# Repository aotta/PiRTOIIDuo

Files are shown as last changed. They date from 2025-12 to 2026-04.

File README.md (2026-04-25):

# PiRTOIIDuo
New PiRTO multicart for Intellivision with JLP support, based on Raspberry Pico2 

PiRTO II DUO is the new version of my PiRTO multicart DIY yourself based now on a Raspberry Pi Pico2 for using double RAM.

This version support Intellivision bin+cfg games, including the JLP acceleration and savegames features.
It works with all games i testes since now, except for "Onion" (it's a big rom and i think it will need next pico3 ;) )

changelog:
v.1.00 - initial release

v.1.01 - bugfix in parsing cfg

v.1.02 - added parsing for "jlp_accel" params, improved overclock for "Onion"

v.1.03 - increaded RAMSIZE to 0x4000 from 0x2000, bug fixed for YM-Player

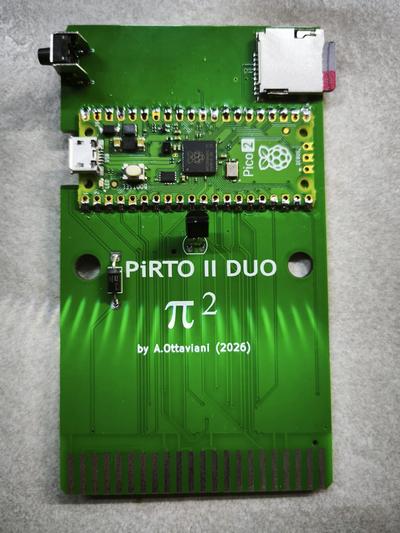
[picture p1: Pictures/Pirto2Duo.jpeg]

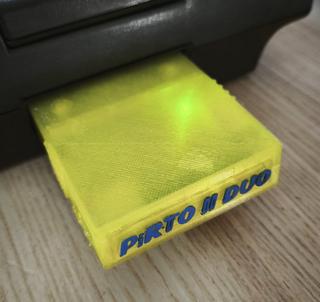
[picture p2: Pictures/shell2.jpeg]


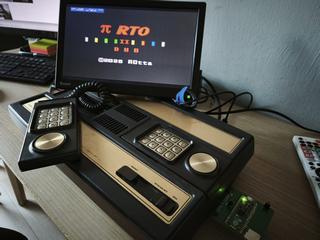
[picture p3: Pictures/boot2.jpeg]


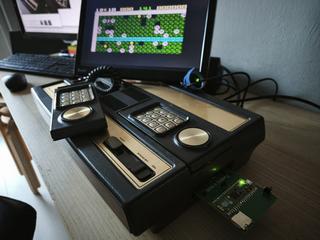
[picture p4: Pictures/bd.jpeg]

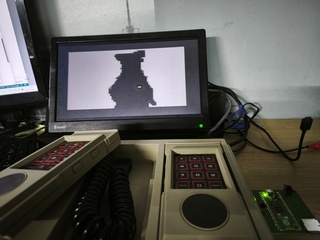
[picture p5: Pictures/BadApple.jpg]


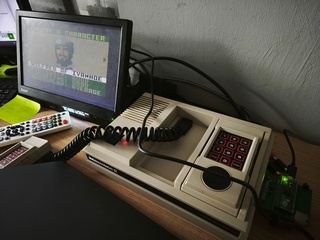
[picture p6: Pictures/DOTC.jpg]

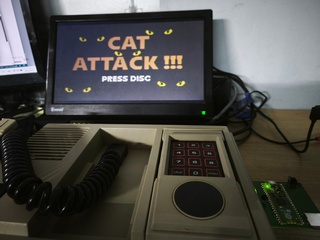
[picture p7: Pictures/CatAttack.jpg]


Kicad project and gerbers files for the pcb are in the PCB folder, you need only a diode, a push buttons for resetting the cart if needed or want restart, and the micro SDCard holder. 
Add you pico2, and flash the firmware ".uf2" in the Pico by connecting it while pressing button on Pico and drop it in the opened windows on PC.
Use the SDCard to store "BIN" and "CFG“ files  into.

3D files for shell coming soon!

More info on AtariAge forum: [https://forums.atariage.com/](https://forums.atariage.com/topic/386798-pirto-ii-duo-powered-by-pico2-with-jlp-support/)

Even if the diode should protect your console, **DO NOT CONNECT PICO WHILE INSERTED IN A POWERED ON CONSOLE!**
You can use any schottky diode, i usually put 1n4148

## Credits
This upgrade is dedicated to Mariella, with love and gratitude for trusting me and encouraging me to never give up

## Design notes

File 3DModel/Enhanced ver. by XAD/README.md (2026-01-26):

Here are some improvements that i have made to the PiRTO-II Duo cartridge cover:

- Reduced the hole for inserting the Mini SD Card. (Unless you have fingers big as sausages, you can easily remove and insert the Mini SD Card. I've seen much worse situations.)
- Added new PCB support bracket. (When inserting the Mini SD Card, the PCB flexed downward)
- Added hole for the Raspberry Pi Pico2 button. (Useful for updating the PiRTO-II Duo without opening the cartridge)
- Added hole for the USB connector. (Useful for updating the PiRTO-II Duo without opening the cartridge)
- Increased thickness of the front/top internal cartridge support.
- Slightly narrowed the hole for resetting/restarting the cartridge to use the button cover.

=-=-=-=-=-=-=-=-=-=-=-=-=-=-=-=-=-=-=-=-=-=-=-=-=-=-=-=-=-=-=-=-=-=-=-=-=-=-=-=-=-=-=-=-=-=-=-=-=-=-=-=-=-=-=-=-=-=-=-=-=-=-=-=-=-=

Ecco alcune migliorie che ho fatto alla cover della cartuccia PiRTO-II Duo.

- Ridotto il foro per inserire la Mini SDCard. (Almeno che tu non abbia della dita grosse come una salsicca si riesce benissimo a rimuovere e inserire la Mini SDCard,  ho visto situazioni molto peggiori)
- Aggiunto nuovo supporto per il PCB. (infilando la Mini SDCard il pcb si fletteva in basso)
- Aggiunto foro per il pulsante della Raspberry Pi Pico2. (utile per aggiornare la PiRTO-II Duo senza aprire la cartuccia)
- Aggiunto foro per il connettore USB.  (utile per aggiornare la PiRTO-II Duo senza aprire la cartuccia)
- Aumentato lo spessore del supporto interno frontale/superiore della cartuccia.
- Ristretto leggermente il foro del reset/restart cartuccia per utilizzare il copri pulsante.

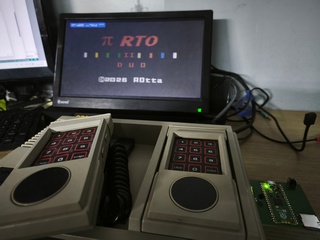
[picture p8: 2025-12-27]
Pictures/PiRTOIIDuo.jpg

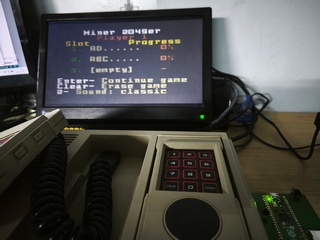
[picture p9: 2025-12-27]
Pictures/Miner2049.jpg

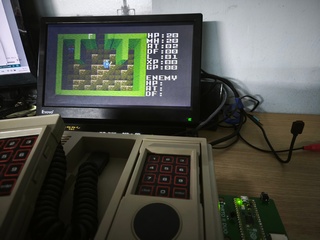
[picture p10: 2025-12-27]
Pictures/TalesofDragon.jpg

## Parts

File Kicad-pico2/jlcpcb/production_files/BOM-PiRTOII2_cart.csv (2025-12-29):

Comment | Designator | Footprint | LCSC | Quantity
1n5819 | D1 | D_DO-41_SOD81_P10.16mm_Horizontal | C2474 | 1
BC547 | Q1 | TO-92L_HandSolder | C2092 | 1
BTN_RESET_PICO | SW1 | SW_Tactile_SPST_Angled_PTS645Vx83-2LFS | C918856 | 1
Micro_SD_Card | J3 | J_SD_Card-micro_socket_A | C393941 | 1
PICO | U1 | RPi_Pico_SMD_TH | C41407547 | 1
EDGE_CONN | CN1 | Intellivision_Edge_Connector |  | 1

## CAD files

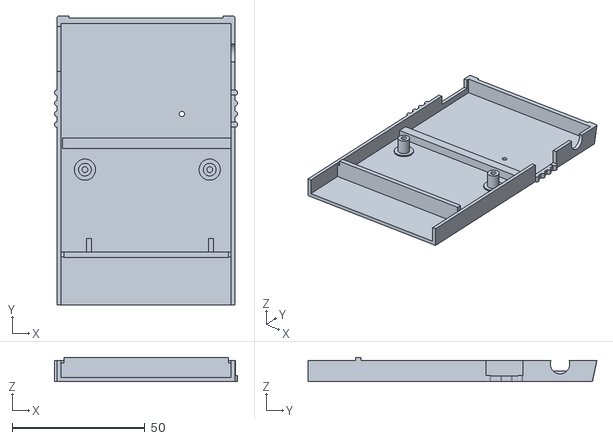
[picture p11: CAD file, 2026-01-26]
3DModel/Enhanced ver. by XAD/PiRTOIIDuo_Cart-Top_(Meshed)-Xad_Nightfall-v2.stl
69.0 x 108.9 x 9.18

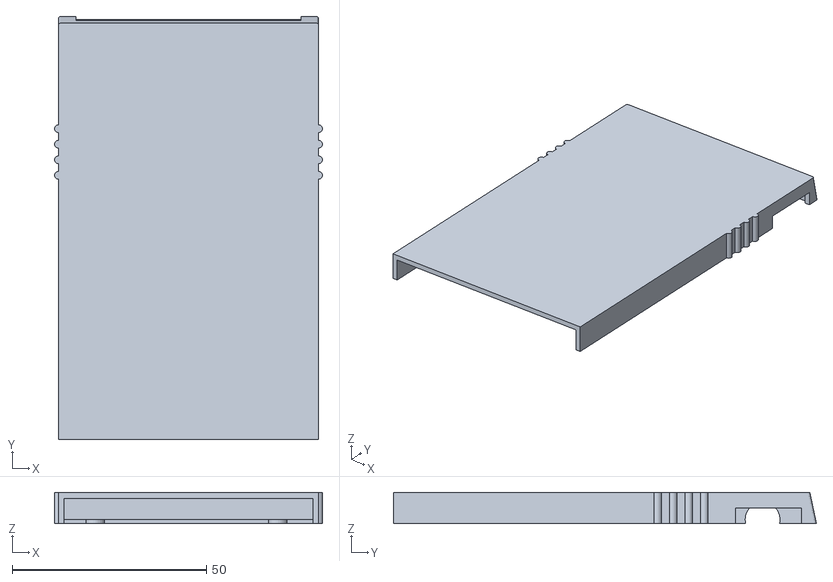
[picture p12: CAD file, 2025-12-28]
3DModel/Original/PiRTOIIDuo_Cart-Top (Meshed).stl
69.0 x 108.9 x 8.00

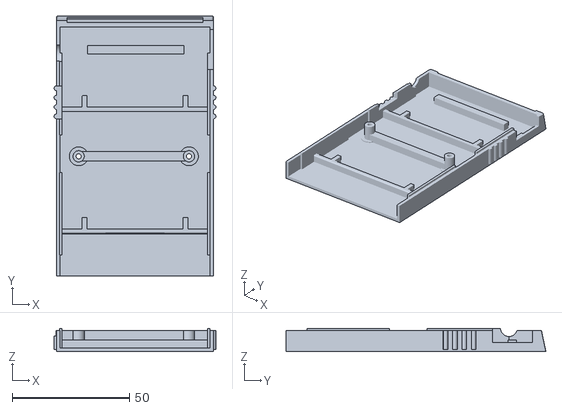
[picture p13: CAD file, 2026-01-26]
3DModel/Enhanced ver. by XAD/PiRTOIIDuo_Cart-Bottom_(Meshed)-Xad_Nightfall-v2.stl
69.0 x 110.8 x 10.00

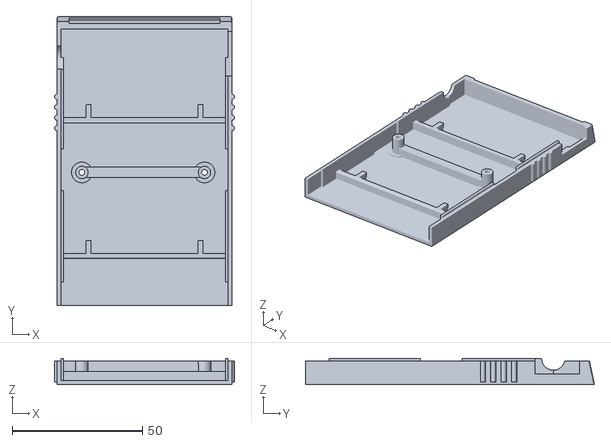
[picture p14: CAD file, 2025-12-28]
3DModel/Original/PiRTOIIDuo_Cart-Bottom (Meshed).stl
69.0 x 110.8 x 10.0

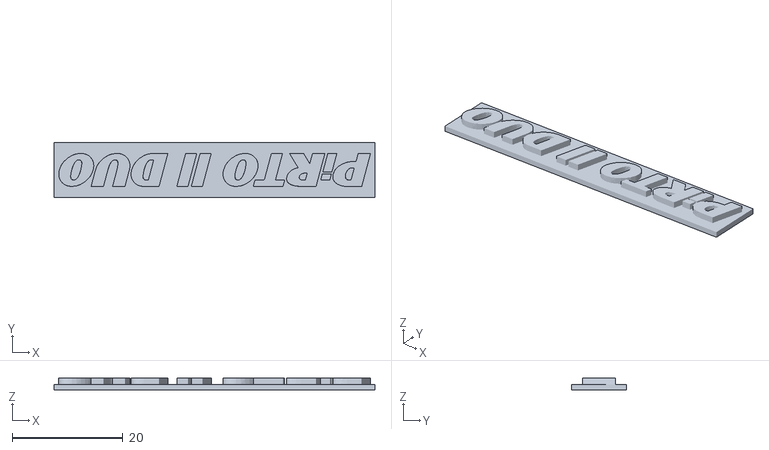
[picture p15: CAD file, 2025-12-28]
3DModel/Original/PiRTOIIDuo_Cart-Logo (Meshed).stl
58.0 x 10.0 x 2.10

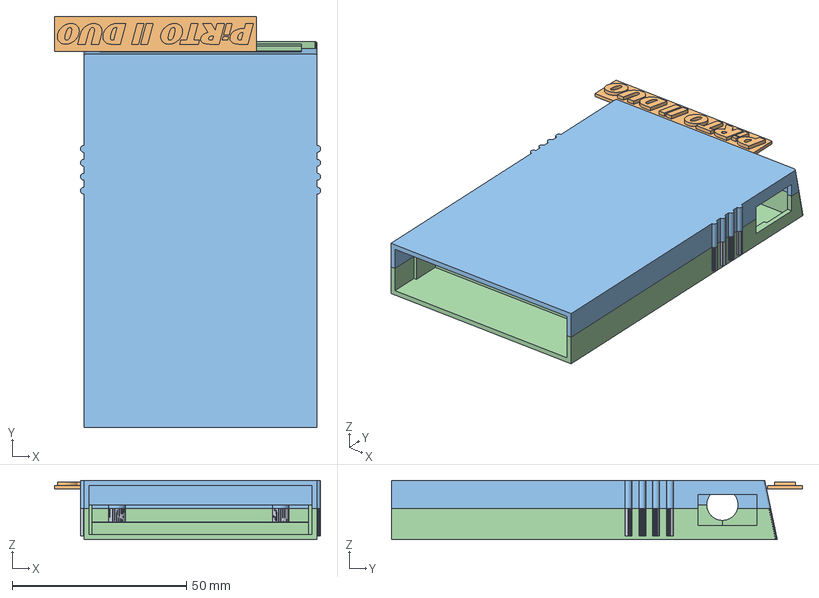
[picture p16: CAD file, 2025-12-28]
3DModel/Original/PiRTOIIDuo_Cart.FCStd
76.5 x 118.0 x 17.0 mm
Bottom
Logo (Meshed)
Top (Meshed)
Bottom (Meshed)

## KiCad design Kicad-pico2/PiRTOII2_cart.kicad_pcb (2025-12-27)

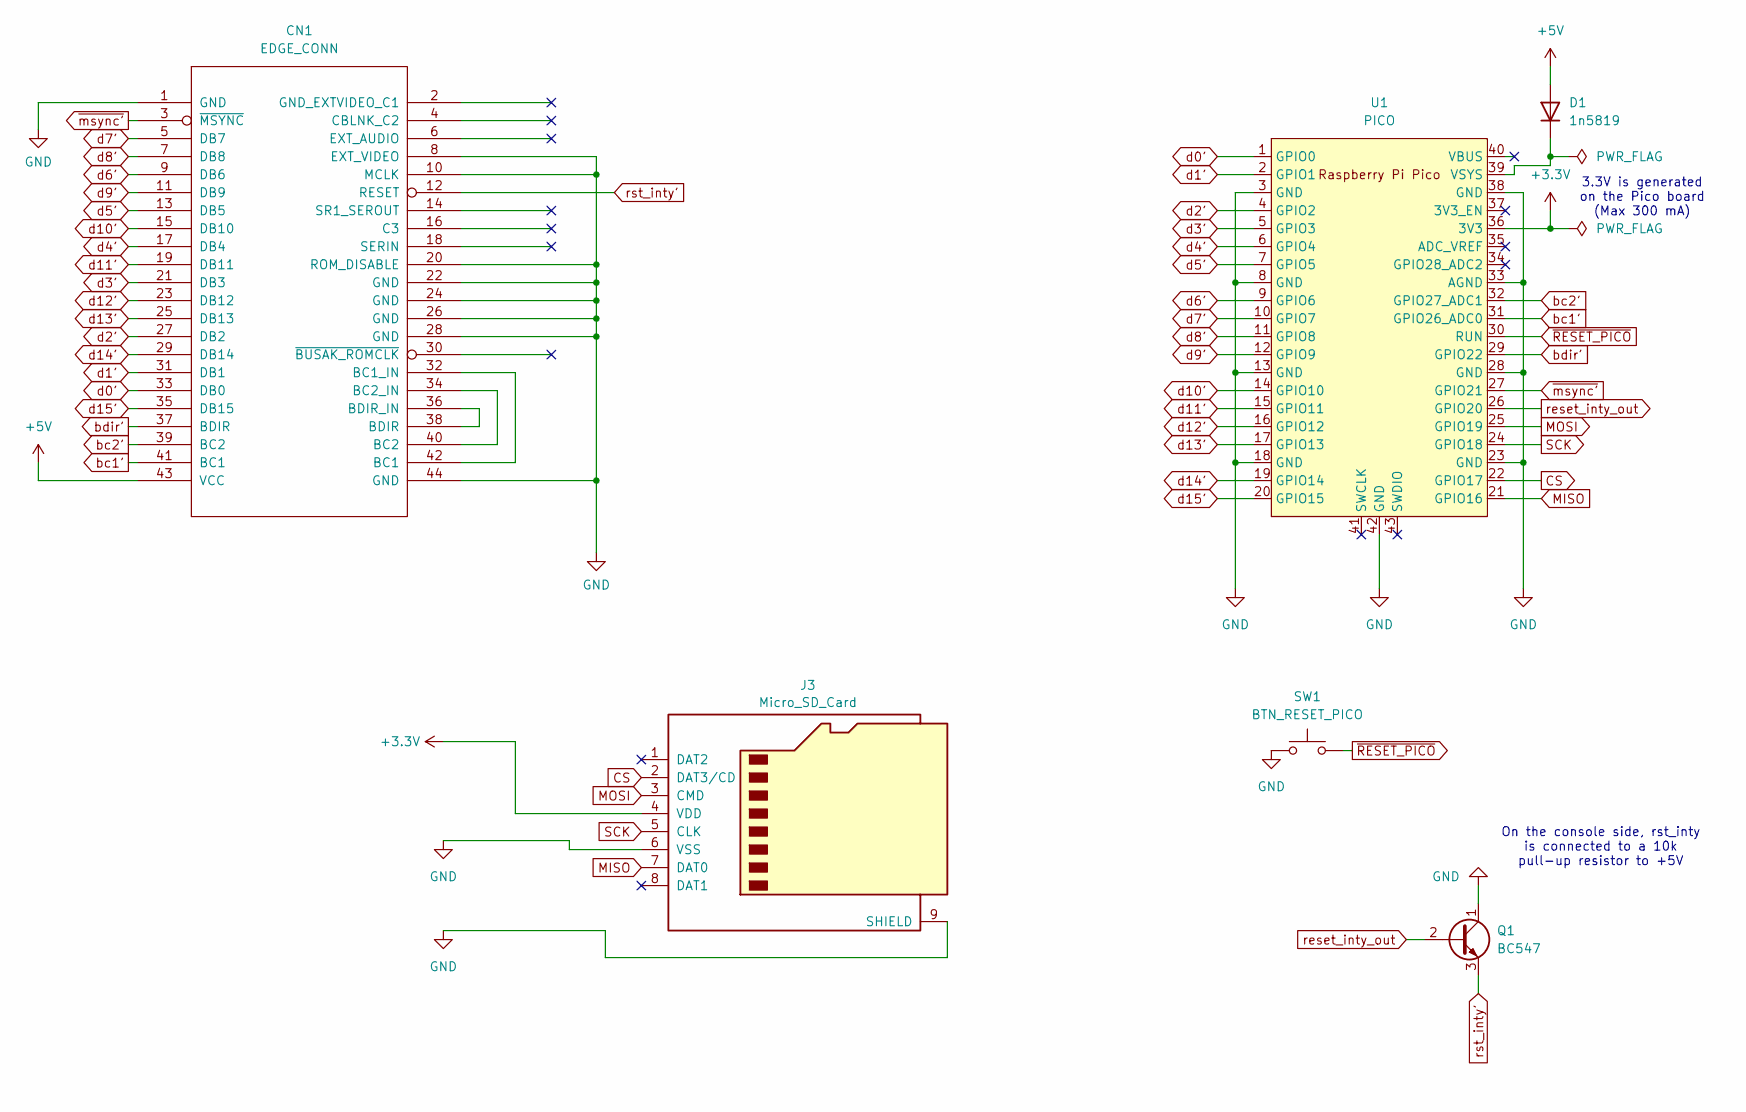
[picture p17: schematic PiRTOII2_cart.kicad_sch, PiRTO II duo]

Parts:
CN1: EDGE_CONN; Intellivision_Edge_Connector
D1: 1n5819; D_DO-41_SOD81_P10.16mm_Horizontal
J3: Micro_SD_Card; J_SD_Card-micro_socket_A
Q1: BC547; TO-92L_HandSolder
SW1: BTN_RESET_PICO; SW_Tactile_SPST_Angled_PTS645Vx83-2LFS
U1: PICO; RPi_Pico_SMD_TH

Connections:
+3.3V: J3.4 (VDD), U1.36 (3V3)
+5V: CN1.43 (VCC), D1.2 (A)
CS: J3.2 (DAT3/CD), U1.22 (GPIO17)
GND: CN1.1 (GND), CN1.8 (EXT_VIDEO), CN1.10 (MCLK), CN1.20 (ROM_DISABLE), CN1.22 (GND), CN1.24 (GND), CN1.26 (GND), CN1.28 (GND), CN1.44 (GND), J3.6 (VSS), J3.9 (SHIELD), Q1.1 (C), SW1.1, U1.3 (GND), U1.8 (GND), U1.13 (GND), U1.18 (GND), U1.23 (GND), U1.28 (GND), U1.33 (AGND), U1.38 (GND), U1.42 (GND)
MISO: J3.7 (DAT0), U1.21 (GPIO16)
MOSI: J3.3 (CMD), U1.25 (GPIO19)
unnamed: CN1.32 (BC1_IN), CN1.42 (BC1)
unnamed: CN1.34 (BC2_IN), CN1.40 (BC2)
unnamed: CN1.36 (BDIR_IN), CN1.38 (BDIR)
unnamed: D1.1 (K), U1.39 (VSYS)
SCK: J3.5 (CLK), U1.24 (GPIO18)
bc1': CN1.41 (BC1), U1.31 (GPIO26_ADC0)
bc2': CN1.39 (BC2), U1.32 (GPIO27_ADC1)
bdir': CN1.37 (BDIR), U1.29 (GPIO22)
d0': CN1.33 (DB0), U1.1 (GPIO0)
d1': CN1.31 (DB1), U1.2 (GPIO1)
d2': CN1.27 (DB2), U1.4 (GPIO2)
d3': CN1.21 (DB3), U1.5 (GPIO3)
d4': CN1.17 (DB4), U1.6 (GPIO4)
d5': CN1.13 (DB5), U1.7 (GPIO5)
d6': CN1.9 (DB6), U1.9 (GPIO6)
d7': CN1.5 (DB7), U1.10 (GPIO7)
d8': CN1.7 (DB8), U1.11 (GPIO8)
d9': CN1.11 (DB9), U1.12 (GPIO9)
d10': CN1.15 (DB10), U1.14 (GPIO10)
d11': CN1.19 (DB11), U1.15 (GPIO11)
d12': CN1.23 (DB12), U1.16 (GPIO12)
d13': CN1.25 (DB13), U1.17 (GPIO13)
d14': CN1.29 (DB14), U1.19 (GPIO14)
d15': CN1.35 (DB15), U1.20 (GPIO15)
reset_inty_out: Q1.2 (B), U1.26 (GPIO20)
rst_inty': CN1.12 (RESET), Q1.3 (E)
~RESET_PICO: SW1.2, U1.30 (RUN)
~msync': CN1.3 (~MSYNC), U1.27 (GPIO21)

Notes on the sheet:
3.3V is generated on the Pico board (Max 300 mA)
On the console side, rst_inty is connected to a 10k pull-up resistor to +5V

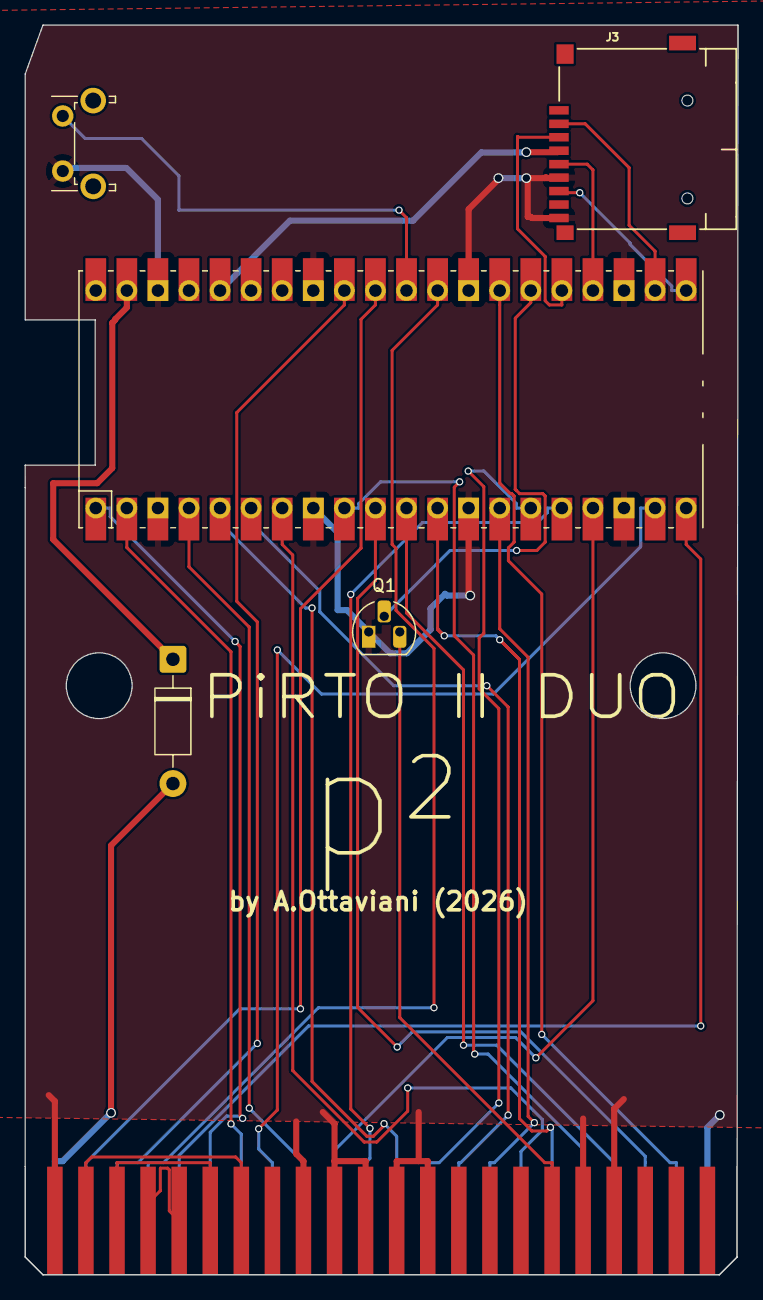
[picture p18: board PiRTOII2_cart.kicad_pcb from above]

Board: 2 copper layers, 58.3 x 102.1 mm, 6 parts (0 on the bottom side), 34 nets.

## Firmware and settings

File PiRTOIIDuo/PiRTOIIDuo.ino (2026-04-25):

/*
//////////////////////////////////////////////////////////////////////////////////////////
//
//                       PiRTO II DUO Flash MultiCART by Andrea Ottaviani 2024
//
//////////////////////////////////////////////////////////////////////////////////////////
//
//  Intellivision flash multicart based on Raspberry Pico2 board -
//  New PiRTO II version with JLP and savegame support
//  More info on https://github.com/aotta/ 
//  
// ***************************************************************************************
//   This upgrade is dedicated to Mariella, with love and gratitude  
//   for trusting me and encouraging me to never give up
// ***************************************************************************************
//
//  v.1.00 - First release 27/12/2025
//  v.1.01 - bug fixed in parsing .cfg with "build date"
//  v.1.02 - added parsing "jlp_accel" in .cfg 
//  v.1.03 - increaded RAMSIZE to 0x4000 from 0x2000, bug fixed for YM-Player
*/

//#define intydebug // for debug print on intyscreen
#define SD_BOARD 
//#define DEFAULT_BOARD 0

#include "hardware/gpio.h"
#include "pico/platform.h"
#include "pico/stdlib.h"
#include "hardware/vreg.h"
#include "pico/multicore.h"
#include "hardware/flash.h"
#include "hardware/sync.h"
#include "string.h"
#include "rom.h"
#include "dir_entry.hpp"
// include for Flash files
#include "SPI.h"
#include "SD.h"

// file system object from SdFat
File file;
File flashFile;
    

// Pico pin usage definitions
#define B0_PIN    0
#define B1_PIN    1
#define B2_PIN    2
#define B3_PIN    3
#define B4_PIN    4
#define B5_PIN    5
#define B6_PIN    6
#define B7_PIN    7
#define F0_PIN    8
#define F1_PIN    9
#define F2_PIN    10
#define F3_PIN    11
#define F4_PIN    12
#define F5_PIN    13
#define F6_PIN    14
#define F7_PIN    15
#define B0_PIN_MASK     0x00000001L     // gpio 0
#define B1_PIN_MASK     0x00000002L
#define B2_PIN_MASK     0x00000004L
#define B3_PIN_MASK     0x00000008L
#define B4_PIN_MASK     0x00000010L
#define B5_PIN_MASK     0x00000020L
#define B6_PIN_MASK     0x00000040L
#define B7_PIN_MASK     0x00000080L
#define F0_PIN_MASK     0x00000100L
#define F1_PIN_MASK     0x00000200L
#define F2_PIN_MASK     0x00000400L
#define F3_PIN_MASK     0x00000800L
#define F4_PIN_MASK     0x00001000L
#define F5_PIN_MASK     0x00002000L
#define F6_PIN_MASK     0x00004000L
#define F7_PIN_MASK     0x00008000L     // gpio 15 
#define RST_PIN   20
#define LED_PIN   25
#define RST_PIN_MASK    0x00100000L // gpio 20
#define LED_PIN_MASK    0x02000000L // gpio 25

// Pico pin usage masks

#ifdef DEFAULT_BOARD
  #define BDIR_PIN  16
  #define BC2_PIN   17
  #define BC1_PIN   18
  #define MSYNC_PIN 19
  #define BDIR_PIN_MASK   0x00010000L // gpio 16
  #define BC2_PIN_MASK    0x00020000L // gpio 17
  #define BC1_PIN_MASK    0x00040000L // gpio 18
  #define MSYNC_PIN_MASK  0x00080000L // gpio 19
  // Aggregate Pico pin usage masks
  #define ALL_GPIO_MASK  	0x021FFFFFL
#else
#ifdef SD_BOARD
   #define MSYNC_PIN 21
   #define BDIR_PIN  22
   #define BC1_PIN   26
   #define BC2_PIN   27
   
   // SD
   #define SD_MISO   16
   #define SD_CS     17
   #define SD_SCK    18
   #define SD_MOSI   19
   #define MSYNC_PIN_MASK  0x00200000L     // gpio 21
   #define BDIR_PIN_MASK   0x00400000L     // gpio 22
   #define BC1_PIN_MASK    0x04000000L     // gpio 26
   #define BC2_PIN_MASK    0x08000000L     // gpio 27
#endif
#endif



  #define BX_PIN_MASK      (B0_PIN_MASK | B1_PIN_MASK | B2_PIN_MASK | B3_PIN_MASK | B4_PIN_MASK | B5_PIN_MASK | B6_PIN_MASK | B7_PIN_MASK)
   #define FX_PIN_MASK     (F0_PIN_MASK | F1_PIN_MASK | F2_PIN_MASK | F3_PIN_MASK | F4_PIN_MASK | F5_PIN_MASK | F6_PIN_MASK | F7_PIN_MASK)
   #define BC1e2_PIN_MASK  (BC1_PIN_MASK | BC2_PIN_MASK)
   #define DATA_PIN_MASK   (BX_PIN_MASK | FX_PIN_MASK)
   #define BUS_STATE_MASK  (BDIR_PIN_MASK | BC1_PIN_MASK | BC2_PIN_MASK)
   #define ALWAYS_IN_MASK  (BUS_STATE_MASK | MSYNC_PIN_MASK)
   #define ALWAYS_OUT_MASK (LED_PIN_MASK|RST_PIN_MASK )


#define SET_DATA_MODE_OUT   gpio_set_dir_out_masked(DATA_PIN_MASK)
#define SET_DATA_MODE_IN    gpio_set_dir_in_masked(DATA_PIN_MASK)

#define resetLow()  gpio_set_dir(RST_PIN,true); gpio_put(RST_PIN,true); //  Pirto to INTV BUS ; RST Output set to 0
#define resetHigh() gpio_set_dir(RST_PIN,true); gpio_put(RST_PIN,false); // RST is INPUT; B->A, INTV BUS to TEENSY

// Inty bus values (BC1+BC2+BDIR) GPIO 26-27-22

#define BUS_NACT  0b000  //0
#define BUS_BAR   0b001  //1
#define BUS_IAB   0b010  //2
#define BUS_DWS   0b011  //3
#define BUS_ADAR  0b100  //4
#define BUS_DW    0b101  //5
#define BUS_DTB   0b110  //6
#define BUS_INTAK 0b111  //7

#define JLP_CRC_POLY 0xAD52

unsigned char busLookup[8];

char RBLo,RBHi;
#define BINLENGTH  1024*218//65536L
#define RAMSIZE  0x4000  // V.1.03 - increaded from 0x2000, bug fixed for YM-Player
#define FLASHSIZE  0x1800  //xx row da 96 0x1800 poi rimettere!!!

uint16_t ROM[BINLENGTH];
uint16_t RAM[RAMSIZE];

#define maxHacks 32
uint16_t HACK[maxHacks];
uint16_t HACK_CODE[maxHacks];

char curPath[256];
char path[256];
unsigned char files[255*70] = {0}; // 255*64 poi rimettere!!!!!!!!!!
unsigned char nomefiles[32*25] = {0};
int fileda=0,filea=0;
volatile char cmd=0;
char errorBuf[40];
bool cmd_executing=false;
volatile bool gameloaded=false;
volatile bool JLPOn=false;
volatile bool pagingOn=false;
volatile bool FlashingOn=false;
volatile unsigned int parallelBus2;
volatile uint8_t curBank;
volatile uint8_t curPage2;
unsigned int romLen;
volatile unsigned int ramfrom = 0;
volatile unsigned int ramto =   0;
unsigned int mapfrom[80];
unsigned int mapto[80];
unsigned int maprom[80];
int mapdelta[80];
unsigned int mapsize[80];
unsigned int addrto[80];
unsigned int RAMused = 0;
volatile bool RAM8 = false;
unsigned int tipo[80];  // 0-rom / 1-page / 2-ram
unsigned int page[80];  // page number
uint8_t curPage[16];
bool segmentedPage[16];


unsigned int slot;
// Variabili globali per il conteggio degli slot
unsigned int Slot0 = 0;  // Conteggio slot con tipo[] = 0
unsigned int Slot1 = 0;  // Conteggio slot con tipo[] = 1
int hacks;

int base=0x17f;

uint32_t selectedfile_size;    // BIN file size
char flashFilename[80];         // for check if directory
int lenfilename; 
char tiposcelta[9];
bool pressed=false;


////////////////////////////////////////////////////////////////////////////////////
//                     RESET
////////////////////////////////////////////////////////////////////////////////////
void resetCart() {
  gpio_init(MSYNC_PIN);
  gpio_set_dir(MSYNC_PIN,false);
  gpio_set_pulls(MSYNC_PIN,false,true);
  gpio_put(LED_PIN,false);
  resetHigh();
   sleep_ms(30);  // was 20 for Model II; 30 works for both
   resetLow();
  //sleep_ms(3);  // was 2 for Model II; 3 works for both
 
  //while ((gpio_get(MSYNC_PIN)==1)) ;
    
  sleep_ms(1);  // was 1 for Model II; 
  resetHigh();
  memset(curPage,0,sizeof(curPage));
  memset(segmentedPage,0,sizeof(segmentedPage));
  
  gpio_put(LED_PIN,true);
}


/*
 Theory of Operation
 -------------------
 Inty sends command to mcu on cart by writing to 50000 (CMD), 50001 (parameter) and menu (50002-50641) 
 Inty must be running from RAM when it sends a command, since the mcu on the cart will
 go away at that point. Inty polls 50001 until it reads $1.
*/

#pragma GCC push_options
#pragma GCC optimize ("O3")


/////////////////////////////////////////////////
void __time_critical_func(setup1()) {   //HandleBUS()
  unsigned int lastBusState, busState1;
  unsigned int busSt1, busSt2;
  unsigned int parallelBus;

  
//from data bus routine
  bool deviceAddress = false; 
  unsigned int dataOut;
  unsigned int dataWrite=0;
  unsigned char busBit;
  uint8_t seg;
  uint16_t curCRC = 0;

  // multicore_lockout_victim_init();	

  randomSeed(millis());
 

  sleep_ms(480);
  busState1 = BUS_NACT;
  lastBusState = BUS_NACT;
  
  dataOut=0;

    gpio_set_dir_in_masked(ALWAYS_IN_MASK);
    gpio_set_dir_out_masked(ALWAYS_OUT_MASK);
 
    // Initial conditions
    SET_DATA_MODE_IN;
   memset(curPage,0,sizeof(curPage));
  
while(1) {
    // Wait for the bus state to change
    
  do {
    } while (!((gpio_get_all() ^ lastBusState) & BUS_STATE_MASK));
    // We detected a change, but reread the bus state to make sure that all three pins have settled
     lastBusState = gpio_get_all();

      busState1 = ((lastBusState & BC1_PIN_MASK) >> (BC1_PIN - 2)) |
         ((lastBusState & BC2_PIN_MASK) >> (BC2_PIN - 1)) |
         ((lastBusState & BDIR_PIN_MASK) >> BDIR_PIN);

    busBit = busLookup[busState1];
    // Avoiding switch statements here because timing is critical and needs to be deterministic
    if (!busBit)
    {
      // -----------------------
      // DTB
      // -----------------------
      // DTB needs to come first since its timing is critical.  The CP-1600 expects data to be
      // placed on the bus early in the bus cycle (i.e. we need to get data on the bus quickly!)
	    if (deviceAddress)
      {
        // The data was prefetched during BAR/ADAR.  There isn't nearly enough time to fetch it here.
        // We can just output it.
        SET_DATA_MODE_OUT;
        gpio_put_masked(DATA_PIN_MASK,dataOut);
        asm inline ("nop;nop;nop;nop;nop;");
  
            //sukkopera 
       while((gpio_get_all() & BC1e2_PIN_MASK) == BC1e2_PIN_MASK) ;

       SET_DATA_MODE_IN;
      }
     }
    else
    {
      busBit >>= 1;
      if (!busBit)
      {
        // -----------------------
        // BAR, ADAR
        // -----------------------
	    if (busState1==BUS_ADAR) {
	     
        if (deviceAddress)  
      		{
        // The data was prefetched during BAR/ADAR.  There isn't nearly enough time to fetch it here.
        // We can just output it.
       
       	SET_DATA_MODE_OUT;
        gpio_put_masked(DATA_PIN_MASK,dataOut);
  //      asm inline ("nop;nop;nop;");
  
        while (((gpio_get_all() & BC1_PIN_MASK)>>BC1_PIN)); //wait BC1 go down 
        //asm inline (delWR); //150ns

         SET_DATA_MODE_IN;
        
      		}
	    }
        /// ELSE is BAR   
        // Prefetch data here because there won't be enough time to get it during DTB.
        // However, we can't take forever because of all the time we had to wait for
        // the address to appear on the bus.
        // We have to wait until the address is stable on the bus
        // waiting bus is stable 66 nop at 200mhz is ok/85 at 240
       
        SET_DATA_MODE_IN;
          parallelBus=0;
        while(((parallelBus=gpio_get_all()) & BDIR_PIN_MASK));  // wait DIR go low for finish BAR cycle 
       asm inline("nop;nop;nop;nop;");
       //asm inline (delRD); //150ns
    
      parallelBus = gpio_get_all()& 0xFFFF; 
      parallelBus2=parallelBus; //poivia
   // Load data for DTB here to save time

      deviceAddress = false;
      if (((parallelBus>=0x8000)&&(parallelBus<=0x9fff))&&(JLPOn)) {  
            deviceAddress = true;
            dataOut=RAM[parallelBus-0x8000];
        if ((parallelBus>=0x802d)&&(parallelBus<=0x802f)) {  //handling flashing command here to avoid de-sync
          if (!FlashingOn) {
            dataOut=0xffff;   //non togliere!!!
          } 
        }   
      } 
      else 
      {  //not jlp
      //  curBank=99;
          
          for (int8_t i=0; i < slot; i++) {
            if (((parallelBus - maprom[i]) <= mapsize[i])){
              deviceAddress = true;     
              if (tipo[i]==2) {
                 dataOut=RAM[parallelBus-ramfrom];
                deviceAddress = true;
                break;
              }
              if (tipo[i]==0) {
                  dataOut=ROM[(parallelBus - mapdelta[i])];
                  break;
              }
              if (tipo[i]==1) {
                seg=(parallelBus>>12)&0xf;   
                if (page[i]==curPage[seg]) {
                  dataOut=ROM[(parallelBus - mapdelta[i])];
                  break;
                } else {dataOut=0xffff;}
              }
            } 
          }
          
      } //if not jlp
        if (hacks>0) {
          for (int i=0; i<maxHacks;i++) {
            if (parallelBus==HACK[i]) {
              dataOut=HACK_CODE[i];
              deviceAddress = true;
	          }
            break;
          }
        } 
      }
      else
      {
         busBit >>= 1;
        if (!busBit)
        {
          // -----------------------
          // DWS WRITE
          // -----------------------
          SET_DATA_MODE_IN;

            if ((pagingOn)&&((parallelBus&0xfff)==0x0fff)) {
              if ((((dataWrite=gpio_get_all() & 0xffff) >> 4) & 0xff) == 0xA5) {
                seg=(parallelBus>>12)&0xf;   
                curPage[seg]=dataWrite & 0xf;
                curPage2=curPage[seg];
              }
            } //else // keep it!!
           if ((deviceAddress)) {
                //  asm inline ("nop;nop;nop;");
            dataWrite = gpio_get_all() & 0xFFFF; 
            if (((parallelBus>=0x8000)&&(parallelBus<=0x9fff))&& JLPOn) {
          //  if (((parallelBus>=0x8000)&&(parallelBus<=0x9fff))) {
              RAM[parallelBus-0x8000]=dataWrite;  
              if (parallelBus==0x9ffc) { // ha scritto 9ffc
                curCRC=RAM[0x1ffd];
                curCRC ^= RAM[0x1ffc];
                for (int i = 0; i < 16; i++) {
                  curCRC = (curCRC >> 1) ^ (curCRC & 1 ? 0xAD52 : 0);
                }
                RAM[0x1ffd]=curCRC;
                }
            } else
             { 
            if ((parallelBus>=ramfrom)&&(parallelBus<=ramto)) {
              if (RAM8) {
                RAM[parallelBus-ramfrom]=dataWrite & 0xFF;
              } else {
                RAM[parallelBus-ramfrom]=dataWrite;
              }
            } 
           }
          }
         else
        {
         // -----------------------
         // NACT, IAB, DW, INTAK
         // -----------------------
         // reconnect to bus
           SET_DATA_MODE_IN;
        }
        
        }
      } 
    }    
  }
} 

#pragma GCC pop_options


////////////////////////////////////////////////////////////////////////////////////
//                     Error(N)
////////////////////////////////////////////////////////////////////////////////////
void error(int numblink){
  Serial.print("Error ");
  Serial.println(numblink);
  while(1){
    gpio_set_dir(25,GPIO_OUT);
    
    for(int i=0;i<numblink;i++) {
      gpio_put(25,true);
      sleep_ms(600);
      gpio_put(25,false);
      sleep_ms(500);
      Serial.print("Error ");
      Serial.println(numblink);
    }
  sleep_ms(2000);
  }
}

/////////////////////////////////
// print on mfile on inty
////////////////////////////////
void printInty(char *temp) {
  for (int i=0;i<120;i++) RAM[0x17f+i]=0;
  for (int i=0;i<60;i++) {
    RAM[0x17f+i*2]=temp[i];
    if (temp[i]==0) {
      RAM[0x17f+i*2]='*';
      break;
    }
  }
  sleep_ms(1000);
} 
int read_directory(char *path) {
  //  if (path[0]==0) strcpy(path,'/');
    Serial.print("Read_directory: ");
    Serial.println(path);
    int ret = 0;
    num_dir_entries = 0;
    DIR_ENTRY *dst = (DIR_ENTRY *)&files[0];

    File dir=SD.open(path, O_RDONLY);
    if (dir) {
        File file;
        while (num_dir_entries < 90 && (file= dir.openNextFile())) {
            char filename[60];
            String(file.name()).toCharArray(filename,60);
            //Serial.println(filename);
            if (strcmp(filename, ".") == 0 || strcmp(filename, "..") == 0) {
                file.close();
                continue;
            }
            
            if ((strcmp(filename,"System Volume Information")==0) ||
            (strcmp(filename,"FOUND.000")==0))
            {
              // Serial.print(filename);Serial.println(" skipped!");
                file.close();
                continue;
            }
  
            dst->isDir = file.isDirectory();
            if (!dst->isDir && !is_valid_file(filename)) {
                file.close();
                continue;
            }
            
            // Usa lo stesso nome per entrambi i campi
            strncpy(dst->long_filename, filename, 31);
            dst->long_filename[31] = 0;
            strncpy(dst->filename, filename, 24);
            dst->filename[24] = 0;
            
            dst->full_path[0] = 0;
            dst++;
            num_dir_entries++;
            
            file.close();
        }
        dir.close();
        
        qsort((DIR_ENTRY *)&files[0], num_dir_entries, sizeof(DIR_ENTRY), entry_compare);
        ret = 1;
    }
    else {
        Serial.println("Can't read directory");
    }
    
    return ret;
}
/////////////////////////////////////////////////////////////////////////////////////////
///////////////////////////////* load file in  ROM */////////////////////////////////////
/////////////////////////////////////////////////////////////////////////////////////////

void load_file(char *filename) {
	
  int car_file = 0;
  int  size = 0;
	Serial.print("load file: ");
  Serial.println(filename);
  //printInty("loadfile");
  //printInty(filename);

 
	if (!(file=SD.open(filename))) {
		Serial.print("Can't open file ");
    Serial.println(filename);
    delay(2000);
    error(2);
	}

 Serial.println("Start load");
 size=0;
 while ((file.available()) && (size<(BINLENGTH-1))) {
  
    RBHi = file.read();
    RBLo = file.read();
   
    if (size<=(BINLENGTH-1)) ROM[size]= RBLo | (RBHi << 8);
   // if (size==0xbafd) Serial.print(size,HEX);Serial.print("-");Serial.println(ROM[size],HEX);
	  size++;
  }
  if (size>=(BINLENGTH-1)){ 
    Serial.println(size);
    Serial.println("Max size exceeded");
    /////while(1) {Serial.print("Error size ");}
    error(4);
  }
closefile:
  romLen=size;
  RAM[base+202]=romLen;
  Serial.print("Len: ");Serial.println(romLen);
  Serial.println("------start game!");
  file.close();
}
// Funzione per leggere una riga dal file
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
void loop()
{
    uint32_t pins;
    uint32_t addr;
    uint32_t dataOut=0;
    uint16_t dataWrite=0;
 
  Serial.println("Loop");

	// overclocking isn't necessary for most functions - but XEGS carts weren't working without it
	// I guess we might as well have it on all the time.
  vreg_set_voltage(VREG_VOLTAGE_1_20);
  set_sys_clock_khz(270000, true);
 
  //multicore_launch_core1(core1_main);

  // Initialize the bus state variables
  // Inty bus values (BC1+BC2+BDIR) GPIO 18-17-16
  // Inty bus values (BC1+BC2+BDIR) GPIO 26-27-22
  busLookup[BUS_NACT]  = 4; // 100
  busLookup[BUS_BAR]   = 1; // 001
  busLookup[BUS_IAB]   = 4; // 100
  busLookup[BUS_DWS]   = 2; // 010   // test without dws handling
  busLookup[BUS_ADAR]  = 1; // 001
  busLookup[BUS_DW]    = 4; // 100
  busLookup[BUS_DTB]   = 0; // 000
  busLookup[BUS_INTAK] = 4; // 100


  gpio_init_mask(ALWAYS_OUT_MASK||ALWAYS_IN_MASK);
  gpio_init_mask(DATA_PIN_MASK);
  gpio_init_mask(BUS_STATE_MASK);
  gpio_set_dir_in_masked(ALWAYS_IN_MASK);
  gpio_set_dir_out_masked(ALWAYS_OUT_MASK);
  gpio_init(LED_PIN);
  gpio_put(LED_PIN,true); 
  gpio_init(RST_PIN);
  
  gpio_set_dir(MSYNC_PIN,GPIO_IN);
  gpio_pull_down(MSYNC_PIN);
  
  sleep_ms(800);
#ifdef intidebug
  RAM[0x163]=2; //1 for debug, 2 for debug with looping
#endif

  resetHigh(); 
  sleep_ms(30);
  resetLow();
  //while (gpio_get(MSYNC_PIN)==1); // wait for Inty powerup
  Serial.println("Inty Pow-ON");
  
  gpio_put(LED_PIN,true);
  memset(ROM,0,BINLENGTH);
  
  for (int i=0;i<(sizeof(_acpirtoIIDuo)/2);i++) {
   ROM[i]=_acpirtoIIDuo[(i*2)+1] | (_acpirtoIIDuo[i*2] << 8);
  }
  //memset(RAM,0,sizeof(RAM));
  //for(int i=0;i<sizeof(RAM);i++) RAM[i]=0;;
  
 for (int i=0; i<maxHacks; i++) {
  HACK[i]=0;
  HACK_CODE[i]=0;
 }

  slot=2; // 2 slots per splash

  //  [mapping]
  //$0000 - $0dFF = $5000
  mapfrom[0]=0x0;
  mapto[0]=0xdff;
  maprom[0]=0x5000;
  tipo[0]=0;
  page[0]=0;
  addrto[0]=0x5dff;
  mapdelta[0]=maprom[0] - mapfrom[0];
  mapsize[0]=mapto[0] - mapfrom[0];
    
 //[memattr]
 //$8000 - $9FFF = RAM 16
  RAMused=1;
  ramfrom=0x8000;
  ramto=0x9fff;
  mapfrom[1]=0x8000;
  mapto[1]=0x9fff;
  maprom[1]=0x8000;
  tipo[1]=2;
  page[1]=0;
  addrto[1]=0x9fff;
  mapdelta[1]=maprom[1] - mapfrom[1];
  mapsize[1]=mapto[1] - mapfrom[1];
  
  //sleep_ms(200);
  //resetCart();
  sleep_ms(200);
  resetCart();
  sleep_ms(1200);
  // Initial conditions 
  memset(curPath,0,sizeof(curPath));
  curPath[0]='/';
  Serial.print("Curpath:");
  Serial.println(curPath);
  sleep_ms(800);
	
  RAM[0x889]=0;
  sleep_ms(800);
	RAM[0x119]=1;
   	 
  RAM[0x119]=123;
   gpio_put(LED_PIN,true);
  
  
  IntyMenu(1);
  
  while (1) {
     cmd_executing=false;
     cmd=RAM[0x889];
     RAM[0x119]=0;
 
     if ((cmd>0)&&!(cmd_executing)) {
      switch (cmd) {
      case 1:  // read file list
        cmd_executing=true;
        RAM[0x889]=0;
    	  IntyMenu(1);
	 	    RAM[0x119]=1;
      	sleep_ms(600);
        Serial.print("new path:");Serial.println(curPath);
      	break;
      case 2:  // run file list
        cmd_executing=true;
    	  RAM[0x889]=0;
	 	    LoadGame();
		    RAM[0x119]=1;
      	sleep_ms(600);
      	break;
      case 3:  // next page
	      cmd_executing=true;
        RAM[0x889]=0;
        IntyMenu(2);
		    RAM[0x119]=1;
        Serial.println("next page");
        sleep_ms(600);
      	break;
      case 4:  // prev page
        cmd_executing=true;
        RAM[0x889]=0; 
     	  IntyMenu(3);
		    RAM[0x119]=1;
        Serial.println("prev page");
        sleep_ms(600);
	 	    break;
	    case 5:  // up dir
        cmd_executing=true;
        RAM[0x889]=0; 
     	  DirUp();
		    IntyMenu(1);
		    RAM[0x119]=1;
        sleep_ms(600);
        Serial.print("Dirup->new path:");Serial.println(curPath);
	 	    break;
    }     
   }
  }
}
#pragma GCC pop_options 	

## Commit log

2025-12-28 added 3d files for shell
    [PiRTOIIDuo_Cart-Bottom (Meshed).stl, PiRTOIIDuo_Cart-Logo (Meshed).stl, PiRTOIIDuo_Cart-Top (Meshed).stl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]
2025-12-29 v.1.01 bug fix
    fixed cfg parsing "build_date" row
    [PiRTOIIDuo.ino]
2026-01-26 added enh. version by XAD-nightfall
    [PiRTOIIDuo_Cart-Bottom (Meshed).stl, PiRTOIIDuo_Cart-Bottom_(Meshed)-Xad_Nightfall-v2.stl, PiRTOIIDuo_Cart-Logo (Meshed).stl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]
2026-02-12 Add files via upload
    removed some debug print left in code
2026-04-25 V.1.03
    increaded from 0x2000, bug fixed for YM-Player
    [PiRTOIIDuo.ino]
